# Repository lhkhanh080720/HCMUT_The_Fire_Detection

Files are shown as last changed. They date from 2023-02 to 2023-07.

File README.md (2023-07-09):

# INTRODUCE
Building an automatic fire extinguishing system in a large room when using sensors is quite difficult.
***
# HARDWARE 
#### Block diagram system
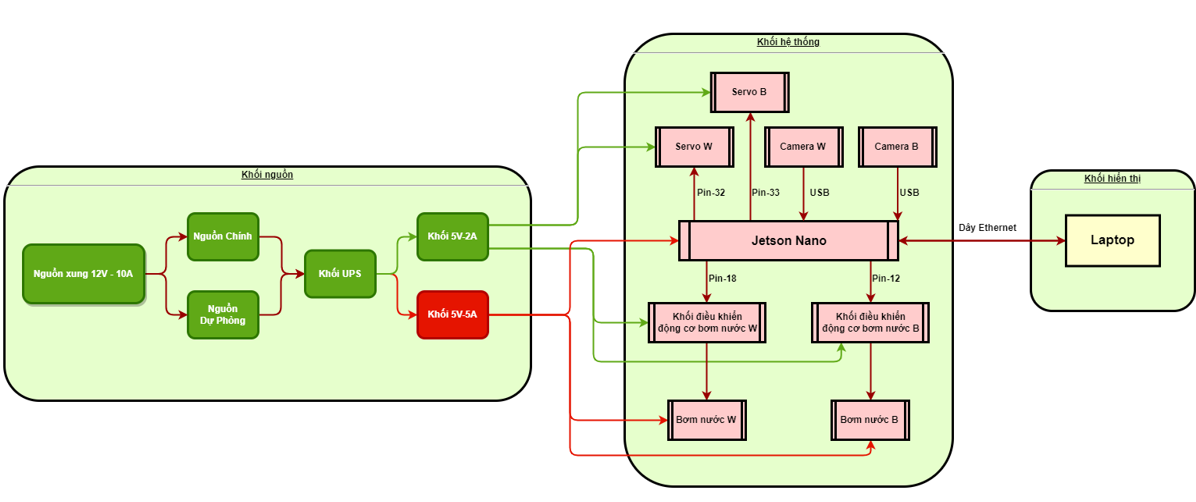
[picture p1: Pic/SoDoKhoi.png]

- **Source Block**: Automatic power switching from the main to backup source when main source has the problem.
- **System Block**: Use Jetson Nano combines with some basic circuits for control servos and water pump.
- **Display Block**: Using an ethernet wire to connect from Jetson Nano to Laptop to control and monitor the system in Jetson Nano. 
#### Using "Altium Designer" to make a circuit
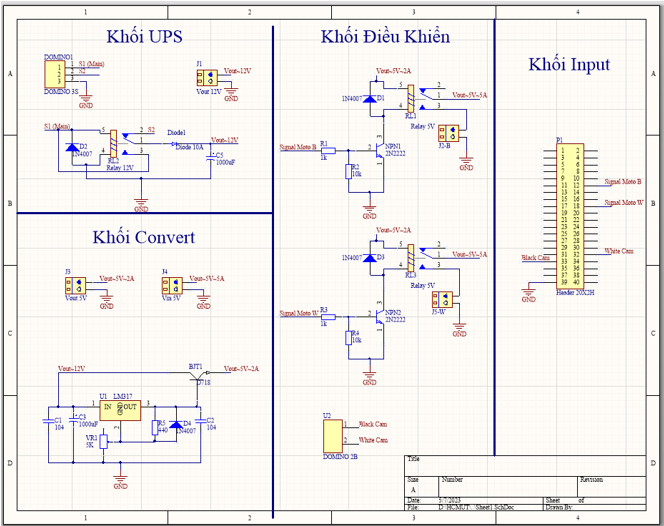
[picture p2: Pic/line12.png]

- Source link: [schematic file][2]

#### Result    
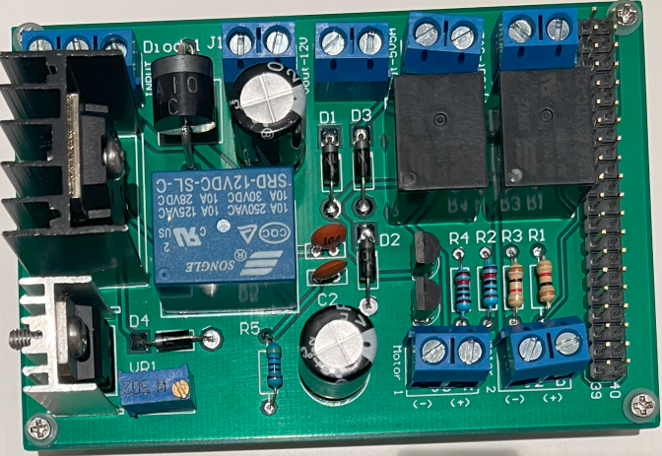
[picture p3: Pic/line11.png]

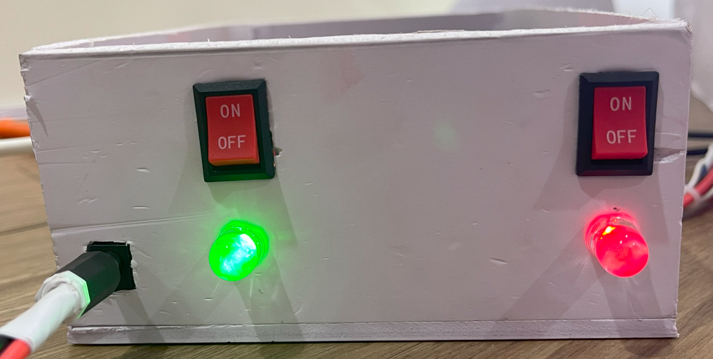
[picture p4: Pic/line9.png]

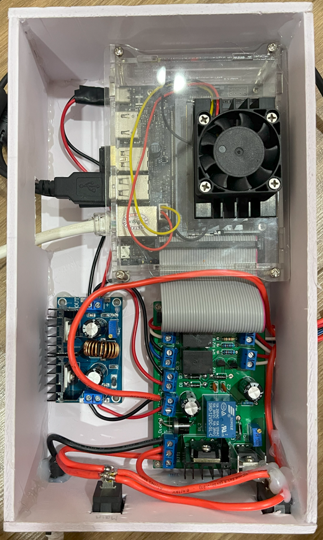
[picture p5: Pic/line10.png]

***
# SOFTWARE 
#### AI
- Using model YOLOv4-tiny and training in Google Colab with:
  - 1 class: fire
  - Epochs: 6000
  - Dataset: ~1000 images
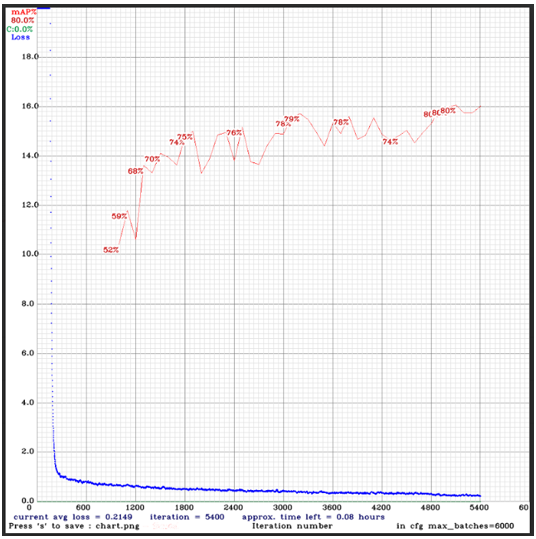
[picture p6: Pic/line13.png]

*(Accuracy ~ 80%)*
  - Testing the model by images, not in dataset:
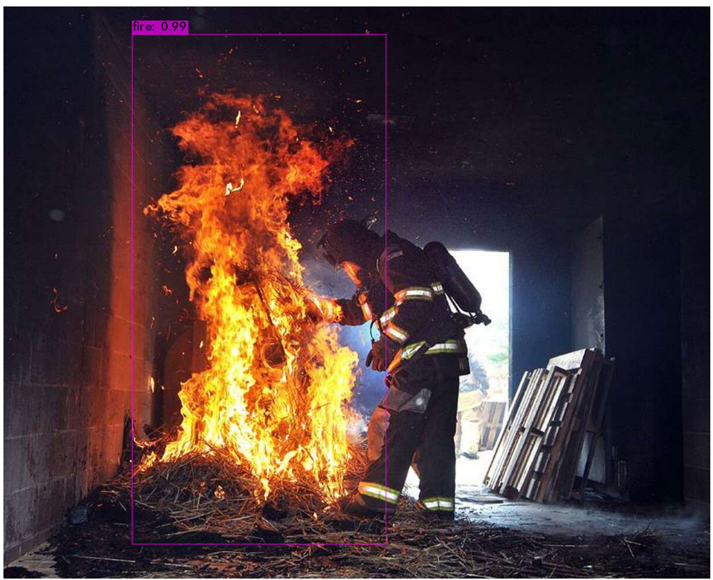
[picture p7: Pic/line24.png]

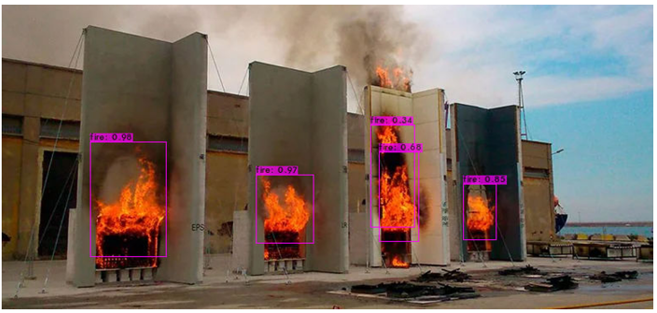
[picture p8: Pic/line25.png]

  - Testing the model by actual video: [Resultvideo.mp4][1]

[1]: <https://github.com/lhkhanh080720/Code_DetectFire/blob/main/Pic/Resultvideo.mp4>
[2]: <https://github.com/lhkhanh080720/Code_DetectFire/blob/main/Hardware/PCB1.PcbDoc>
[3]: <https://github.com/lhkhanh080720/Code_DetectFire/blob/main/Code%20Py%20Win/SystemLastVersion.py>

#### GUI
- The user follows fire detection process. The green line in the middle of the frame is "border" between the two regions. The fire center is the midpoint of the botttom edge of the rectangle. If the fire detection system is in any area, turn on the fire extinguishing system in that area.
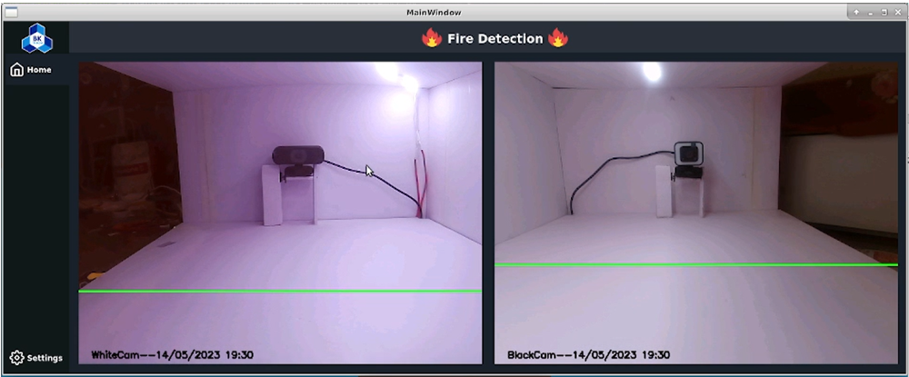
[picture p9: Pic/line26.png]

- When the system detects the fire, layout display 1 will turn red as a warning.
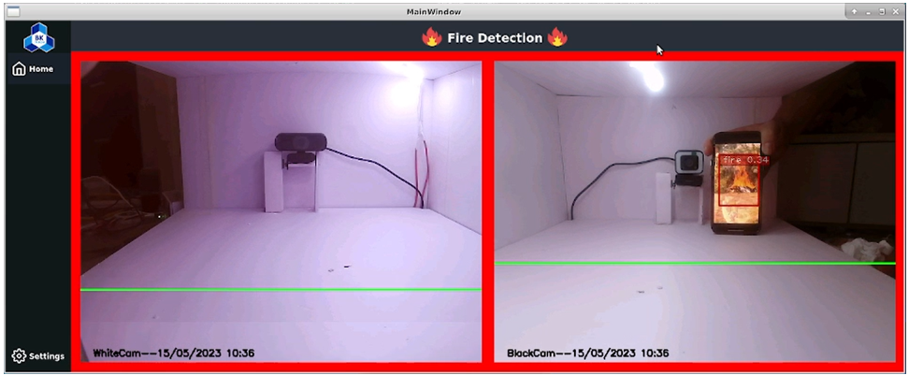
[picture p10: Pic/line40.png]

- After a period of time, the system will automatically move the camera so that it can monitor multiple angles.
- Users can review the system's fire detection process with videos that have been saved on the system.
- Link file: [GUI.py][3]
***
# EVALUATE
#### Hardware
- **Advantage:** UPS system activities without delay, make sure system requests (switch automatically, supply source).  
- **Defect:** if the extinguishing system runs long-term, the voltage drop block will get hot. And all current of the system runs over DIODE 10A then after long-term, it will get hot (the system current is ~ 6A)
#### Software
- **Advantage:** Embedded model into Jetson Nano and running GUI without lag and delay. 
- **Defect:** With objects smaller than the frame, the accuracy of the system is less than 70%. The boundary-finding algorithm is simple

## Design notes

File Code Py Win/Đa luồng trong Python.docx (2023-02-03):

Đa luồng trong Python (Multithreading)

- Thread: đơn vị cơ bản trong CPU. 1 luồng chia sẻ với các luồng khác trong cùng 1 Process về thông tin data, các dữ liệu của mình.
  - Thread là các hàm độc lập trong 1 tiến trình và chạy đọc lập với chương trình chính.
- Multithreading (đa luồng): chứa 2 hay nhiều phần mà có thể chay đồng thời và mỗi phần có thể xử lý tác vụ khác nhau tại cùng 1 thời điểm nếu máy có nhiều CPU.
  - Một Thread có thể bị interrupt hoặc tạm thời dừng (sleeping) trong khi các Thread khác đag chạy đc gọi là yielding.
  - Tuy Thread Module rất hiệu quả với đa luồng tầm thấp nhưng khi so sánh với threading Module có nhiều điểm hạn chế.
- Module Threading: cung cấp nhiều hỗ trợ mạnh mẽ và cấp độ cao hơn cho các Thread tỏng khi so sánh với thread Module ở bên trên.
  - Dừng các thread chứa infinitive loop hoặc ngắt giữa chừng mà không bị ảnh hưởng đến data đó là dùng Daemon Thread

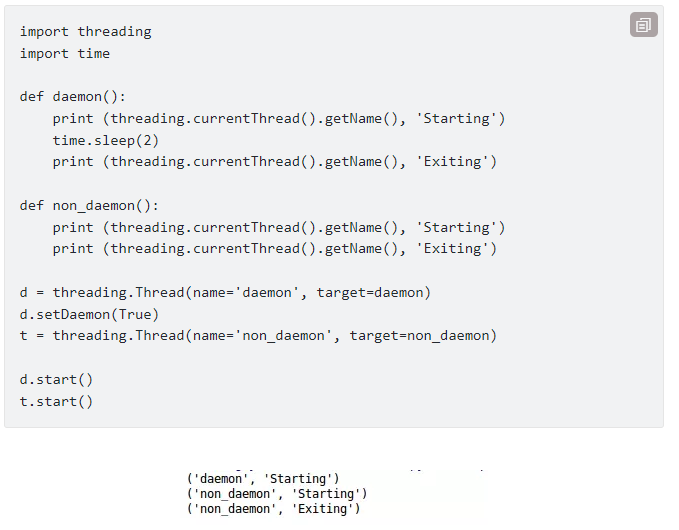
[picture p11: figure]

- Đồng bộ hóa các Thread trong Python: cần đảm bảo tại 1 thời điểm duy nhất chỉ có 1 luồng đc phép truy cập vào data chung, nếu các thread còn lại muốn truy cập thì phải chờ thread trc đó hoàn thành cv của mình => kỹ thuật locking.
  - Phương thức release() của đối tượng lock đc sử dụng để giải phóng lock khi nó không cần nx.

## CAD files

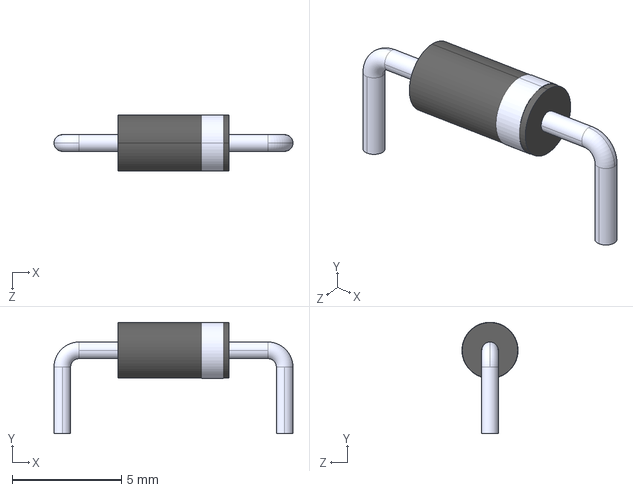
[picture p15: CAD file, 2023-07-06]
Hardware/MyLibs/Link/CircuitWorks-DIODE0_4.step
10.9 x 5.09 x 2.57 mm

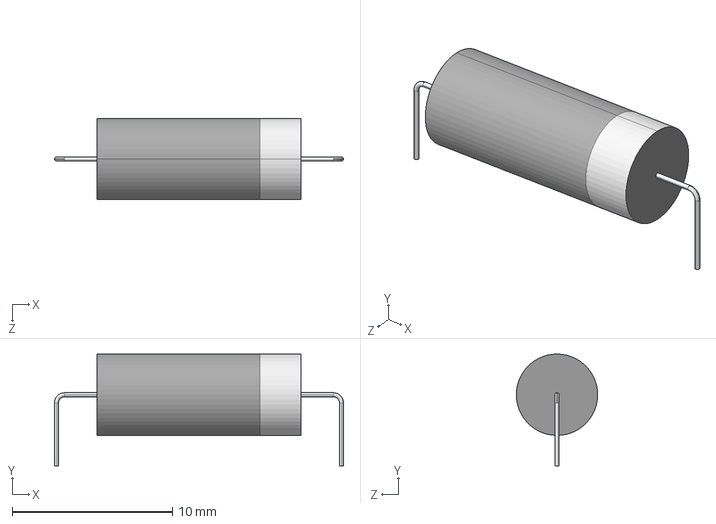
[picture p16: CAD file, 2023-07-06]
Hardware/MyLibs/Link/CircuitWorks-DIODE0_71.step
18.0 x 6.99 x 5.08 mm

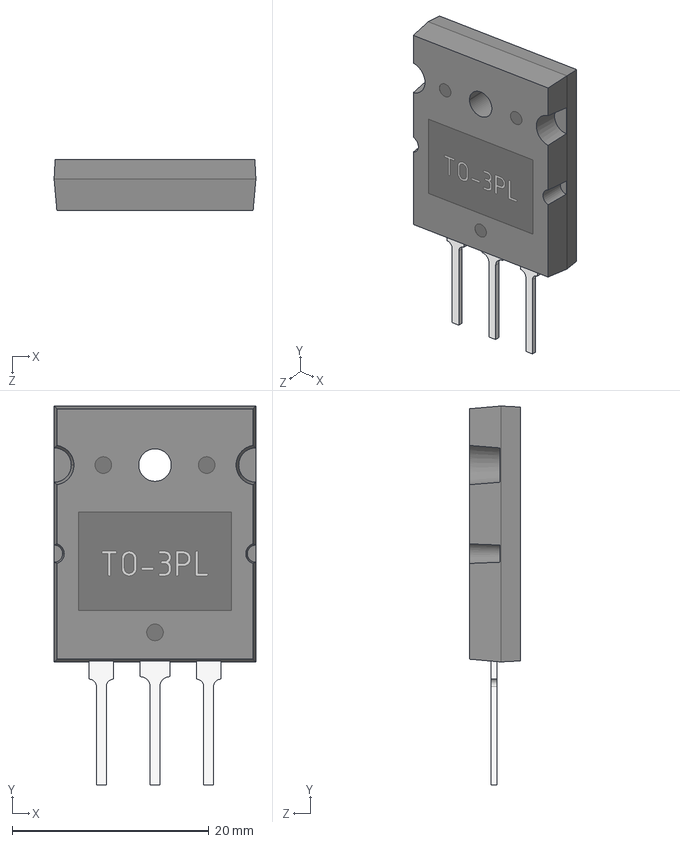
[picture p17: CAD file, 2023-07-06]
Hardware/MyLibs/Link/User Library-TO-3PL_BLACK.STEP
20.5 x 38.5 x 5.20 mm

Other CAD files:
Hardware/MyLibs/Link/CircuitWorks-DIODE0_7.step

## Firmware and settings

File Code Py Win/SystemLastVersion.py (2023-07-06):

# ===============pyuic5 -x ui_interface.ui -o ui_interface.py===============
from libs import *
from PyQt5.QtWidgets import (QWidget, QLabel, QVBoxLayout, QGridLayout, QSizePolicy, QDialog, QPushButton, QTableWidget, QTableWidgetItem, QAbstractItemView, QMessageBox, QApplication)
from PyQt5.QtCore import (QThread, pyqtSignal, pyqtSlot, Qt, QSize, QTimer, QTime, QDate, QObject, QEvent)
from PyQt5.QtGui import (QImage, QPixmap, QFont, QIcon, QColor)
import datetime

import Jetson.GPIO as GPIO

GPIO.setmode(GPIO.BOARD)
WaterW = 18 # PIN (+) in motor W
WaterB = 12 # PIN (+) in motor B

GPIO.setup(WaterW, GPIO.OUT, initial=GPIO.LOW) # control waterW
GPIO.setup(WaterB, GPIO.OUT, initial=GPIO.LOW) # control waterB
GPIO.output(WaterW, GPIO.LOW)
GPIO.output(WaterB, GPIO.LOW)

output_pin1 = 33 #BlackCam
output_pin2 = 32 #WhiteCam
GPIO.setup(output_pin1, GPIO.OUT, initial=GPIO.HIGH)
p1 = GPIO.PWM(output_pin1, 50)
GPIO.setup(output_pin2, GPIO.OUT, initial=GPIO.HIGH)
p2 = GPIO.PWM(output_pin2, 50)
p1.start(7)
indexS1 = [306, 234, 156]
statusS1 = 0
p2.start(6)
indexS2 = [271, 157, 93]#Black CAm
statusS2 = 0

timeB = time.time()
timeW = time.time()

class MAIN_HANDLE(QMainWindow):
    camID1 = "WhiteCam"
    cap1 = cv2.VideoCapture("/dev/video0", cv2.CAP_V4L2)

    camID2 = "BlackCam"
    cap2 = cv2.VideoCapture("/dev/video1", cv2.CAP_V4L2)

    #------for func Notice------
    timeOut = 2
    valueAngle1 = 7
    valueAngle2 = 6

    statusWarning = False

    areaW = False
    areaB = False

    flagControl = False

    statusBtnW = False
    statusBtnB = False

    def __init__(self):
        super().__init__()
        self.uic = Ui_MainWindow()
        self.uic.setupUi(self)

        #Add
        #=================Stack Widget=================#
        self.uic.mainFrame.setCurrentWidget(self.uic.homeF)

        self.uic.menuBtn.clicked.connect(self.show2Cam)
        self.uic.cam1Btn.clicked.connect(self.settingsSystem)
        self.uic.camWBtn.clicked.connect(self.camWBtnFc)
        self.uic.camBBtn.clicked.connect(self.camBBtnFc)
        #=================Add feature=================#
        self.Cam1 = Camera(MAIN_HANDLE.cap1, self.uic.label_3, MAIN_HANDLE.camID1)    
        self.Cam2 = Camera(MAIN_HANDLE.cap2, self.uic.label_4, MAIN_HANDLE.camID2)
        self.Cam1.update_frame()
        self.Cam2.update_frame()
        # Update Camera
        self.timer1 = QtCore.QTimer()
        self.timer1.timeout.connect(self.Cam1.update_frame)
        self.timer1.timeout.connect(self.Cam2.update_frame)
        self.timer1.start(1)
        # Detect the Fire
        self.timer2 = QtCore.QTimer()
        self.timer2.timeout.connect(self.check_Fire)
        self.timer2.start(1)
        # Move Camera1:
        self.timer3 = QtCore.QTimer()
        self.timer3.timeout.connect(self.move_camera1)
        # self.timer3.start(15000)
        # Move Camera2:
        self.timer4 = QtCore.QTimer()
        self.timer4.timeout.connect(self.move_camera2)
        # self.timer4.start(15000)
        # Feature for 2 widget Cam1 and Cam2
        self.Cam3 = Camera(MAIN_HANDLE.cap1, self.uic.label_5, MAIN_HANDLE.camID1)
        self.Cam4 = Camera(MAIN_HANDLE.cap2, self.uic.label_6, MAIN_HANDLE.camID2)
        self.timer5 = QtCore.QTimer()
        self.timer5.timeout.connect(self.Cam3.update_frame)
        self.timer5.timeout.connect(self.Cam4.update_frame)
        # Warning in system
        self.timer7 = QtCore.QTimer()
        self.timer7.timeout.connect(self.warningFire)
        # Check location of the fire
        self.timer8 = QtCore.QTimer()
        self.timer8.timeout.connect(self.controlWater)

    # Widget 1: Show 2 camera
    def show2Cam(self):
        self.uic.mainFrame.setCurrentWidget(self.uic.homeF)
        self.uic.menuBtn.setStyleSheet("background-color: #1f232a;")
        self.uic.cam1Btn.setStyleSheet("background-color: #16191d;")
        self.timer5.stop()
        self.timer2.start(1)
        self.timer1.start(1)
        self.timer3.start(15000)
        self.timer4.start(15000)
        self.timer8.stop()
        p1.stop()
        p2.stop()
        MAIN_HANDLE.flagControl = False
        
    # Widget 2: Settings
    def settingsSystem(self):
        self.uic.mainFrame.setCurrentWidget(self.uic.cam1F)
        self.uic.menuBtn.setStyleSheet("background-color: #16191d;")
        self.uic.cam1Btn.setStyleSheet("background-color: #1f232a;")
        MAIN_HANDLE.flagControl = True
        GPIO.output(WaterW, GPIO.LOW)
        GPIO.output(WaterB, GPIO.LOW)
        p1.start(7)
        p2.start(6)
        self.timer1.stop()
        self.timer7.stop()
        self.timer8.stop()
        self.timer2.stop()
        self.timer3.stop()
        self.timer4.stop()
        self.timer5.start(1)

    # Btn control Cam W
    def camWBtnFc(self):
        self.uic.camBBtn.setStyleSheet("background-color: #1f232a;")
        self.uic.camWBtn.setStyleSheet("background-color: #16191d;")
        if not MAIN_HANDLE.statusBtnW:
            GPIO.output(WaterW, GPIO.HIGH)
            self.uic.camWBtn.setText("OFF")
        elif MAIN_HANDLE.statusBtnW:
            GPIO.output(WaterW, GPIO.LOW)
            self.uic.camWBtn.setText("ON")
        MAIN_HANDLE.statusBtnW = not MAIN_HANDLE.statusBtnW

    # Btn control Cam W
    def camBBtnFc(self):
        self.uic.camWBtn.setStyleSheet("background-color: #1f232a;")
        self.uic.camBBtn.setStyleSheet("background-color: #16191d;")
        if not MAIN_HANDLE.statusBtnB:
            GPIO.output(WaterB, GPIO.HIGH)
            self.uic.camBBtn.setText("OFF")
        elif MAIN_HANDLE.statusBtnB:
            GPIO.output(WaterB, GPIO.LOW)
            self.uic.camBBtn.setText("ON")
        MAIN_HANDLE.statusBtnB = not MAIN_HANDLE.statusBtnB

    # Detected the Fire
    def check_Fire(self):
        global outVid1, outVid2
        if self.Cam1.flag:
            self.Cam1.countFire = time.time()
            if not self.Cam1.flagFire:
                if not self.timer7.isActive():
                    print("Timer is running")
                    self.timer7.start(700)
                titleVideo = datetime.datetime.now()
                outVid1 = cv2.VideoWriter('Videos/WCam/' + str(titleVideo) + '.avi', cv2.VideoWriter_fourcc(*'XVID'), 30, (640, 480)) # Write the Video with fps = 21
                print("Name video: ", str(titleVideo))
                print("Cam1: Fire!")
                # Control water & led
                if not self.timer8.isActive():
                    self.timer8.start(1)
                self.Cam1.flagFire = True
                self.Cam1.flag0Fire = False 
                self.Cam1.saveCam = True
                self.timer3.stop()
                self.timer4.stop()
                p1.stop()
                p2.stop()
        elif time.time() - self.Cam1.countFire > MAIN_HANDLE.timeOut:
            if not self.Cam1.flag0Fire:
                print("Cam1: no Fire")
                self.Cam1.objectF = 0
                self.Cam1.flagFire = False
                self.Cam1.flag0Fire = True
                self.Cam1.flag = False
                self.timer3.start(15000)
                self.timer4.start(15000)
                self.Cam1.saveCam = False
                outVid1.release()

        if self.Cam2.flag: 
            self.Cam2.countFire = time.time()
            if not self.Cam2.flagFire:
                if not self.timer7.isActive():
                    self.timer7.start(700)
                titleVideo1 = datetime.datetime.now()
                outVid2 = cv2.VideoWriter('Videos/BCam/' + str(titleVideo1) + '.avi', cv2.VideoWriter_fourcc(*'XVID'), 30, (640, 480)) # Write the Video with fps = 21
                print("Name video: ", str(titleVideo1))
                print("Cam2: Fire!")
                # Control water & led
                if not self.timer8.isActive():
                    self.timer8.start(1)
                self.Cam2.flagFire = True
                self.Cam2.flag0Fire = False
                self.Cam2.saveCam = True
                self.timer3.stop()
                self.timer4.stop()
                p1.stop()
                p2.stop()
        elif time.time() - self.Cam2.countFire > MAIN_HANDLE.timeOut:
            if not self.Cam2.flag0Fire:
                print("Cam2: no Fire")
                self.Cam2.flagFire = False
                self.Cam2.flag0Fire = True
                self.Cam2.flag = False
                self.Cam2.objectF = 0
                self.timer3.start(15000)
                self.timer4.start(15000)
                self.Cam2.saveCam = False
                outVid2.release()

        if self.Cam1.flag0Fire and self.Cam2.flag0Fire:
            self.timer7.stop()
            self.timer8.stop()
            self.areaW = False
            self.areaB = False
            self.uic.mainFrame.setStyleSheet("background-color: #1f232a;")    
            GPIO.output(WaterB, GPIO.LOW)
            GPIO.output(WaterW, GPIO.LOW)
            self.Cam1.objectF = 0
            self.Cam2.objectF = 0

    # Control servo to move cam
    def move_camera1(self):
        global statusS1
        p1.start(MAIN_HANDLE.valueAngle1)
        if MAIN_HANDLE.valueAngle1 == 7:
            statusS1 = 0
        else:
            statusS1 += 1
        MAIN_HANDLE.valueAngle1 += 0.5
        if MAIN_HANDLE.valueAngle1 > 8.5:
            MAIN_HANDLE.valueAngle1 = 7
            p1.start(MAIN_HANDLE.valueAngle1)
            statusS1 = 0
            self.timer3.start(15000)
        else:
            self.timer3.start(5000)

    def move_camera2(self):
        global statusS2
        p2.start(MAIN_HANDLE.valueAngle2)
        if MAIN_HANDLE.valueAngle2 == 6:
            statusS2 = 0
        else:
            statusS2 += 1
        MAIN_HANDLE.valueAngle2 += 0.5
        if MAIN_HANDLE.valueAngle2 > 7.5:
            MAIN_HANDLE.valueAngle2 = 6
            p2.start(MAIN_HANDLE.valueAngle2)
            statusS2 = 0
            self.timer4.start(15000)
        else:
            self.timer4.start(5000)

    def warningFire(self):
        if not MAIN_HANDLE.statusWarning:
            self.uic.mainFrame.setStyleSheet("background-color: rgb(255, 0, 0);")
        elif MAIN_HANDLE.statusWarning:
            self.uic.mainFrame.setStyleSheet("background-color: #1f232a;")
        if not MAIN_HANDLE.statusWarning:
            MAIN_HANDLE.statusWarning = True
        elif MAIN_HANDLE.statusWarning:
            MAIN_HANDLE.statusWarning = False
    
    def controlWater(self):
        global statusS1, statusS2, indexS1, indexS2, timeW, timeB
        if len(self.Cam1.objectF) > 0:
            for index, value in enumerate(self.Cam1.objectF):
                if value <= indexS1[statusS1]:
                    self.areaB = True 
                    self.areaW = False or self.areaW
                elif value > indexS1[statusS1]:
                    self.areaW = True
                    self.areaB = False or self.areaB
        else:
            self.areaB = False
            self.areaW = False

        if len(self.Cam2.objectF) > 0:
            for index, value in enumerate(self.Cam2.objectF):
                if value <= indexS2[statusS2]:
                    self.areaW = True 
                    self.areaB = False or self.areaB
                elif value > indexS2[statusS2]:
                    self.areaB = True
                    self.areaW = False or self.areaW
        else:
            self.areaW = False or self.areaW
            self.areaB = False or self.areaB

        if self.areaB:
            print("area ==>> B")
            if not MAIN_HANDLE.flagControl:
                GPIO.output(WaterB, GPIO.HIGH)
                timeB = time.time()
        else:
            if not MAIN_HANDLE.flagControl and time.time() - timeB >= 2:
                GPIO.output(WaterB, GPIO.LOW)

        if self.areaW:
            print("area ==>> W")
            if not MAIN_HANDLE.flagControl:
                GPIO.output(WaterW, GPIO.HIGH)
                timeW = time.time()
        else:
            if not MAIN_HANDLE.flagControl and time.time() - timeW >= 2:
                GPIO.output(WaterW, GPIO.LOW)
        
        self.areaW = False 
        self.areaB = False

    def clear(self): pass

    def closeEvent(self, event):
        GPIO.output(WaterW, GPIO.LOW)
        GPIO.output(WaterB, GPIO.LOW)

        self.timer1.stop()
        self.timer2.stop()
        self.timer3.stop()
        self.timer4.stop()
        self.timer5.stop()
        self.timer7.stop()
        self.timer8.stop()
        GPIO.cleanup()
        event.accept()

# Class Camera
numClass = 2     #The numbers of classes
cls_dict = get_cls_dict(numClass)
vis = BBoxVisualization(cls_dict)
trt_yolo = TrtYOLO('obj', numClass, False)
class Camera:
    global outVid1, outVid2
    def __init__(self, cam_link, output, camID):
        self.source = cam_link
        self.output = output
        self.camID = camID
        self.flag = False
        self.flagFire = False
        self.flag0Fire = False
        self.countFire = 0
        self.saveCam = False
        self.objectF = 0

    def update_frame(self):   
        global statusS1, statusS2, indexS1, indexS2       
        ret, self.frame = self.source.read()
        if not MAIN_HANDLE.flagControl:
            self.detectObjects(self.frame)
        self.frame = cv2.cvtColor(self.frame, cv2.COLOR_BGR2RGB)
        # add text feature
        now = datetime.datetime.now()
        self.text = self.camID + now.strftime("--%d/%m/%Y %H:%M")
        cv2.putText(self.frame, self.text, (20, 470), cv2.FONT_HERSHEY_SIMPLEX, 0.5, (0,0,0), 2)
        # add line
        if self.camID == "WhiteCam":
            cv2.line(self.frame, (0, indexS1[statusS1]), (640, indexS1[statusS1]), (0, 255, 0), 2)
        elif self.camID == "BlackCam":
            cv2.line(self.frame, (0, indexS2[statusS2]), (640, indexS2[statusS2]), (0, 255, 0), 2)
        
        if MAIN_HANDLE.flagControl:
            self.frame = cv2.resize(self.frame, (600, 450))

        image = QImage(self.frame, self.frame.shape[1], self.frame.shape[0], QImage.Format_RGB888)
        self.output.setPixmap(QPixmap.fromImage(image))
        # save frame
        if self.saveCam:
            if self.camID == "WhiteCam":
                outVid1.write(cv2.cvtColor(self.frame, cv2.COLOR_RGB2BGR))
            elif self.camID == "BlackCam":
                outVid2.write(cv2.cvtColor(self.frame, cv2.COLOR_RGB2BGR))

    def detectObjects(self, frame):  
        global vis, trt_yolo
        boxes, confs, clss = trt_yolo.detect(frame, 0.3)
        #Precise poison filter (> 0.6)
        indexDel = []
        for index, value in enumerate(confs):
            if value <= 0.7:
                indexDel.append(index)
        boxes = np.delete(boxes, indexDel, 0)
        confs = np.delete(confs, indexDel)
        clss = np.delete(clss, indexDel)

        if len(confs) > 0: 
            self.frame, y_max = vis.draw_bboxes(frame, boxes, confs, clss)
            self.objectF = y_max
            self.flag = True
        else:
            self.flag = False
            self.objectF = []

if __name__ == "__main__":
    import sys
    app = QApplication(sys.argv)
    main_win = MAIN_HANDLE()
    main_win.show()
    sys.exit(app.exec_())

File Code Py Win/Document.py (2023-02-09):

from functools import partial
from threading import Lock
import numpy as np
import time
import cv2
import os

from PyQt5.QtWidgets import (QWidget, QLabel, QVBoxLayout, QGridLayout, QSizePolicy, QDialog, QPushButton, QTableWidget, QTableWidgetItem, QAbstractItemView, QMessageBox, QApplication)
from PyQt5.QtCore import (QThread, pyqtSignal, pyqtSlot, Qt, QSize, QTimer, QTime, QDate, QObject, QEvent)
from PyQt5.QtGui import (QImage, QPixmap, QFont, QIcon, QColor)

os.environ['OPENCV_VIDEOIO_DEBUG'] = '1'
os.environ['OPENCV_VIDEOIO_PRIORITY_MSMF'] = '0'

# pip uninstall cryptography -y 
# pip install --upgrade cryptography
# pip install pywin32-ctypes
# pip install pyinstaller

# create single installer.exe --onefile IS NOT WORKING because pywin32
# pyinstaller --onefile --windowed --icon icon.png multi_cam_4x4.py

# create directory installer for instead
# pyinstaller --onedir --windowed --icon icon.png multi_cam_4x4.py

# without icon (works), check 'dist/'
# pyinstaller --onefile --windowed multi_cam_4x4.py
# OR
# pyinstaller --onedir --windowed multi_cam_4x4.py


# width, height = 480*4, 640*4
width, height = 480*6, 270*6
# capture_delay = 10000 # 10 seconds
capture_delay = 100 # 100ms , Dont set 1, too fast, crash


# -----------------------------------------
class Thread(QThread):
	imgSignal = pyqtSignal(np.ndarray, int, bool)

	def __init__(self, parent, cam_link, index):
		QThread.__init__(self, parent)
		self._lock = Lock()
		self.p = parent
		self.cam_link = cam_link
		self.index = index

	def run(self):
		# self._lock.acquire()
		with self._lock:
			cap = cv2.VideoCapture(self.cam_link)
			while cap.isOpened():
				has, img = cap.read()
				if not has: break # video has limit
				# img = cv2.resize(img, (img.shape[1]//2, img.shape[0]//2))
				self.imgSignal.emit(img, self.index, True)
				cv2.waitKey(capture_delay) & 0xFF # works, dont set 1, will crash, too fast
			
			img = np.zeros((height,width,3), np.uint8)
			self.imgSignal.emit(img, self.index, False)
			cv2.waitKey(capture_delay) & 0xFF # works, dont set 1, will crash, too fast

	# def stop(self):
	# 	self._lock.release()
	# 	cv2.destroyAllWindows()
	# 	self.cap.release()


# -----------------------------------------
# https://wiki.python.org/moin/PyQt/Making%20non-clickable%20widgets%20clickable
def clickable(widget):
	class Filter(QObject):
		clicked = pyqtSignal()
		def eventFilter(self, obj, event):
			if obj == widget:
				if event.type() == QEvent.MouseButtonRelease:
					self.clicked.emit()
					return True
			return False

	filter = Filter(widget)
	widget.installEventFilter(filter)
	return filter.clicked


# -----------------------------------------
class NewWindow(QDialog):
	def __init__(self, parent):
		QDialog.__init__(self, parent)
		self.p = parent
		self.index = None

		self.label = QLabel()
		self.label.setSizePolicy(QSizePolicy.Ignored, QSizePolicy.Ignored)
		self.label.setScaledContents(True)
		self.label.setFont(QFont("Times", 30))
		self.label.setStyleSheet(
			"color: rgb(255,0,255);"
			"background-color: rgb(0,0,0);"
			"qproperty-alignment: AlignCenter;")

		layout = QVBoxLayout()
		layout.setContentsMargins(0,0,0,0)
		# layout.setSpacing(2)
		layout.addWidget(self.label)
		self.setLayout(layout)
		self.setWindowTitle('Camera {}'.format(self.index))

	def sizeHint(self):
		return QSize(width//4, height//4)

	def resizeEvent(self, event):
		self.update()

	def close(self):
		self.accept()

	def keyPressEvent(self, event):
		if event.key() == Qt.Key_Escape:
			self.accept()


# -----------------------------------------
class TableStatus(QDialog):
	def __init__(self, parent):
		QDialog.__init__(self, parent)
		self.p = parent

		# Table Widget ---------------
		# https://pythonspot.com/pyqt5-table/
		# https://freeprog.tistory.com/333
		# https://likegeeks.com/pyqt5-tutorial/
		self.table = QTableWidget()
		self.table.setSelectionMode(QAbstractItemView.SingleSelection)
		# self.table.setSelectionMode(QAbstractItemView.MultiSelection)
		self.table.setRowCount(len(self.p.cam_links))
		self.table.setColumnCount(2)
		self.table.setHorizontalHeaderLabels(('ID', 'Status')) # NOTE: after setColumnsCount()
		self.table.horizontalHeaderItem(0).setTextAlignment(Qt.AlignCenter)
		self.table.horizontalHeader().setStretchLastSection(True)
		self.table.horizontalHeader().setFont(QFont("Times", 13))
		# self.table.verticalHeader().setStretchLastSection(True)
		# self.table.setSortingEnabled(True)
		style = "::section {""background-color: darkcyan; color: rgb(230,230,230);}"
		self.table.horizontalHeader().setStyleSheet(style)
		self.table.verticalHeader().setStyleSheet(style)
		# self.table.setShowGrid(True)

		self.table.resizeColumnsToContents()
		self.table.resizeRowsToContents()
		# self.table.sortByColumn(0, Qt.AscendingOrder)
		self.table.setEditTriggers(QAbstractItemView.NoEditTriggers) # Read-Only

		# self.table.setSizePolicy(QSizePolicy.Maximum, QSizePolicy.Maximum)

		layout = QVBoxLayout()
		layout.setContentsMargins(0,0,0,0)
		# layout.setSpacing(2)
		layout.addWidget(self.table)
		self.setLayout(layout)
		self.setWindowTitle('Camera Status')

	def sizeHint(self):
		return QSize(width//4, height//4)

	def resizeEvent(self, event):
		self.update()

	def keyPressEvent(self, event):
		if event.key() == Qt.Key_Escape:
			self.accept()
			# self.table.clear()
			self.p.buttonStatus.setStyleSheet(
				"color: rgb(127,255,127); background-color: rgb(0,0,0);")

	def closeEvent(self, event):
		event.accept()
		self.p.buttonStatus.setStyleSheet(
			"color: rgb(127,255,127); background-color: rgb(0,0,0);")

	def updateTable(self, cam_links, actives):
		for i, (cam_link, active) in enumerate(zip(cam_links, actives)):
			# simple
			# self.table.setItem(i,0, QTableWidgetItem(str(cam_link))) # rowi,col0
			# self.table.setItem(i,1, QTableWidgetItem(str(active))) # rowi,col1

			# complex
			col1 = QTableWidgetItem(str(cam_link))
			col1.setFont(QFont("Times", 13))
			col1.setForeground(QColor(127,255,255))				# fg
			if i % 2 == 0: col1.setBackground(QColor(0,0,0))	# bg
			else: col1.setBackground(QColor(61,53,53))			# bg
			col1.setTextAlignment(Qt.AlignLeft)
			self.table.setItem(i,0, col1)

			col2 = QTableWidgetItem(str(active))
			col2.setFont(QFont("Times", 13))
			if active: col2.setForeground(QColor(127,255,127))	# fg
			else: col2.setForeground(QColor(255,127,127))		# fg
			if i % 2 == 0: col2.setBackground(QColor(0,0,0))	# bg
			else: col2.setBackground(QColor(61,53,53))			# bg
			col2.setTextAlignment(Qt.AlignCenter)
			self.table.setItem(i,1, col2)

		self.table.resizeColumnsToContents()
		self.table.resizeRowsToContents()
		# self.resize(QSize(width//4, height//4))

		self.p.buttonStatus.setStyleSheet(
			"color: rgb(255,127,127); background-color: rgb(0,0,0);")
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

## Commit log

2023-01-29 FIx: slow in multicamera
    [Systemv2.py]
2023-02-04 Can't print("hang 3")
2023-02-09 v2: 2 Errors & v3: done
    [Systemv3.py]
2023-02-10 GUI + Thread (but can't use detect)
2023-02-12 Connect Jetson with 2 mg90s (PWM)
2023-02-13 Connect with 2 LedNoti
2023-02-16 Ft with 2 Servo
2023-02-16 Update GUI with only 2 frames in 2 camera
2023-02-28 Save frames of 2 cams in the system
2023-03-16 From Ubuntu
    [obj.cfg]
2023-03-16 Fix: 2 area is OKE
    [SystemLastVersion.py]
2023-03-16 GUI control motor
2023-07-06 Add Hardware
    [2n2222.PcbLib, 2n2222.SchLib, 2sb688.PcbLib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]
